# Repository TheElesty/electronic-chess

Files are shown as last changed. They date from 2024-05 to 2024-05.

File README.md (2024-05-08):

# electronic-chess
### Diploma thesis project

This is my implementation for electronic chess board. It uses NFC MFRC522 for pieces detection. UI consist of TFT LCD display, adressable LED and endstops/rotary encoder for input. 

This repository contains all files needed to manufacture, assemble and program electronic chessboard.

Folders contains
- [board_model](board_model/README.md) - all 3D models created in Fusion 360
- [electronic_chess](electronic_chess/README.md) - whole firmware created in Arduino IDE
- [manufacturing](manufacturing/README.md) - all files for 3D printing (prepared in Bambu studio, Anycubic Workshop and LightBurn)
- [pcb_schematics](pcb_schematics/README.md) - all schematics created in Eagle

Each directory has it own README with instructions, tutorials, etc.

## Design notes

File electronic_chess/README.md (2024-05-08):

# Firmware

This folder contains whole firmware of chess board. It's written in Arduino IDE. All used libraryes are in folder libs, you must copy thes lib into Arduino folder in your PC (some libraries are changed and without it is firmware uncompilable).

Program is tested with [earlephilhower arduino-pico](https://github.com/earlephilhower/arduino-pico/) Raspberry Pi Pico core. You need to add board definition for it - pase this link in Arduino IDE -> preferences -> Aditional boards definitions -> https://github.com/earlephilhower/arduino-pico/releases/download/global/package_rp2040_index.json

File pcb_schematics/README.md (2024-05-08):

# Eagle schematics

This folder contains all schematics used board. Either you can open schematic directli or creat new project and paste files from folder Electronic_chess inside it.

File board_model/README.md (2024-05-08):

# Board model

All parts of chess board is modeled in Fusion360. Thes folder contains both Fusion projects and 3mf export of all parts. PCB models are generated from schematics made in Eagle.

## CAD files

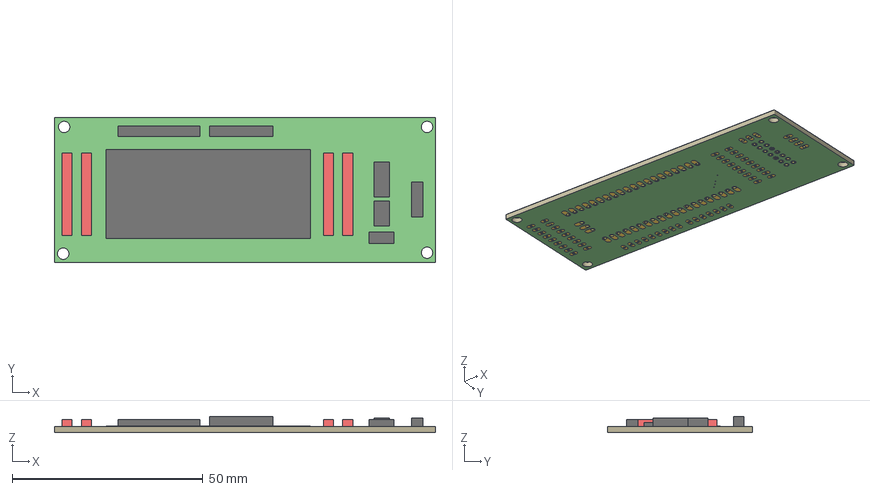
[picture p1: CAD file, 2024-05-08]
board_model/PCB/main_board/main_board v1.3mf
100.0 x 38.0 x 4.31 mm
Board
CopperHoles

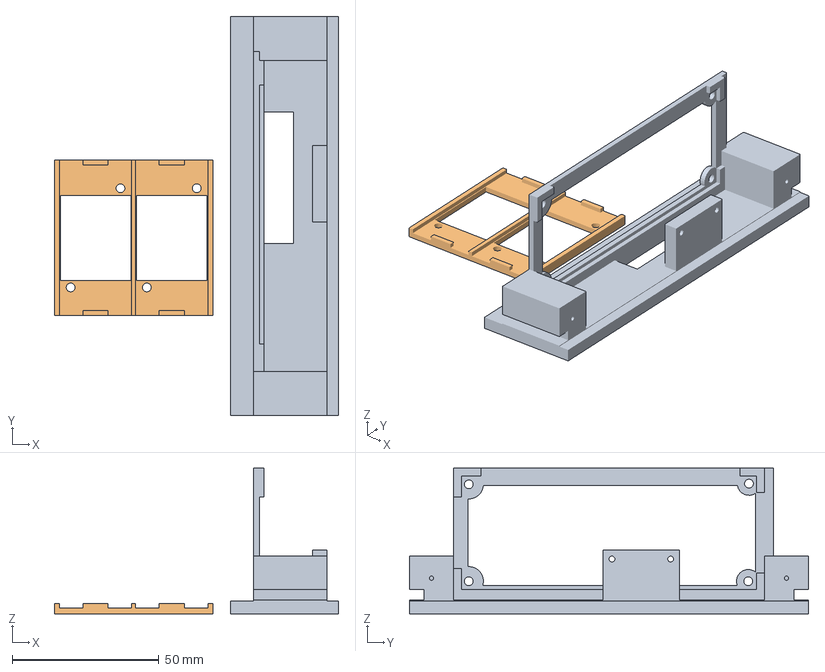
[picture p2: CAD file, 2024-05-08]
manufacturing/printing/chess_board_main_board.3mf
96.8 x 136.0 x 49.7 mm
main_board_holder
powersupply_holder

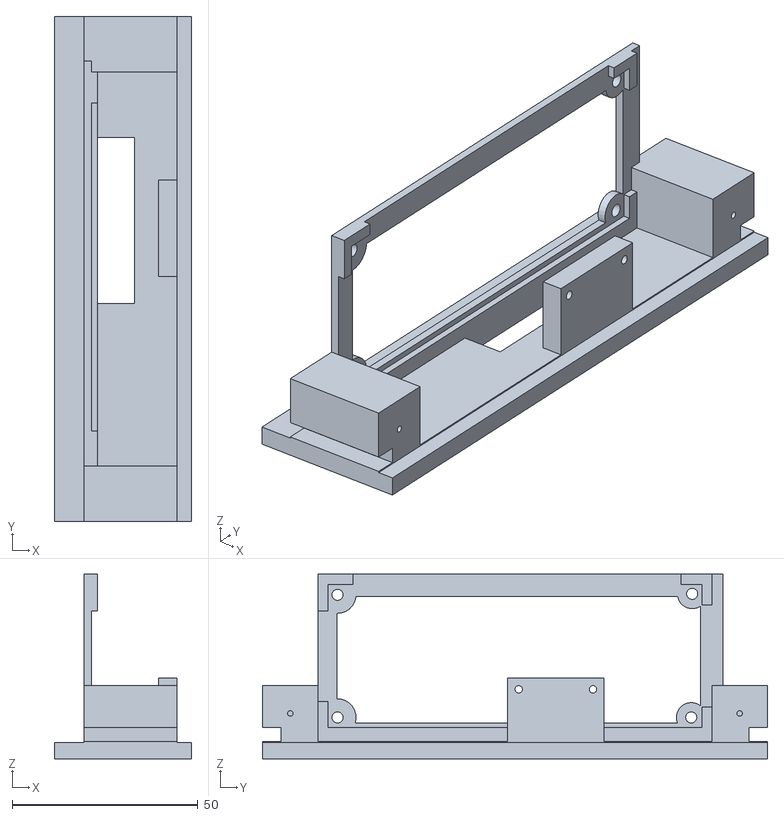
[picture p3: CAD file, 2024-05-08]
manufacturing/printing/raw/chess_board_mainboard_holder.stl
36.9 x 136.0 x 49.7

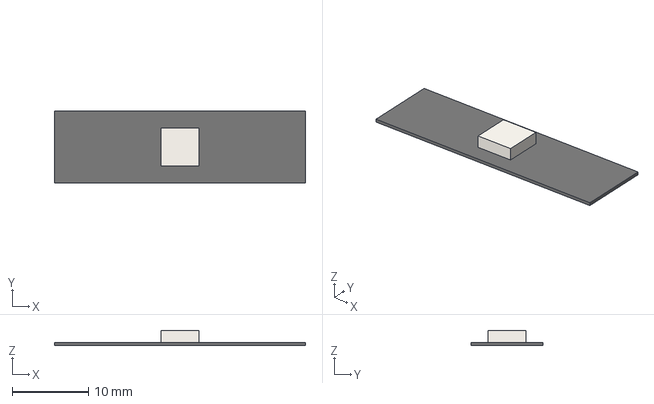
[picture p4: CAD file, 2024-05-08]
board_model/MODELS/Assets/led v2.3mf
33.0 x 9.50 x 2.00 mm

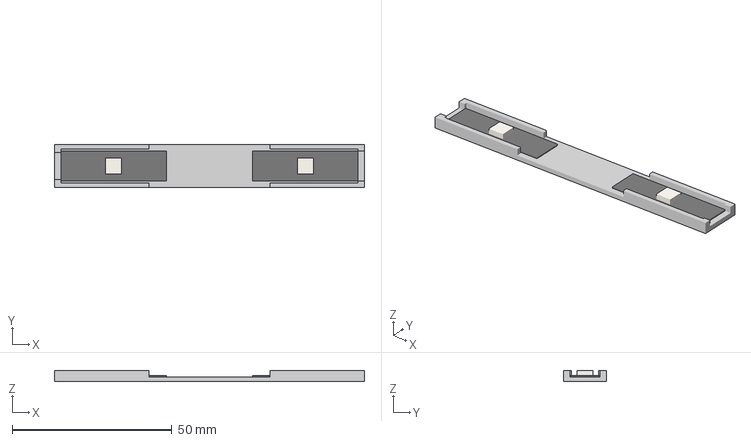
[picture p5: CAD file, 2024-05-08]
board_model/MODELS/led_solderRig v2.3mf
97.0 x 13.5 x 3.50 mm

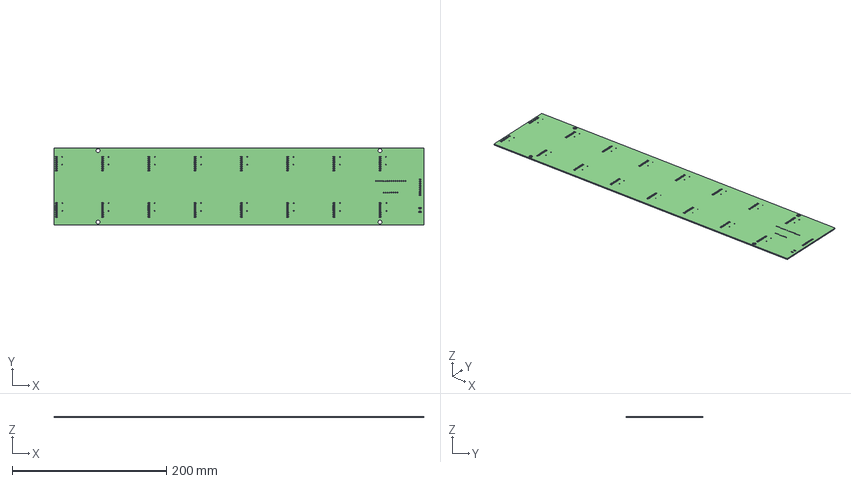
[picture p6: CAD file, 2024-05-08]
board_model/PCB/mux16_board/mux16_board v1.3mf
480.0 x 100.0 x 1.64 mm
Board
CopperHoles

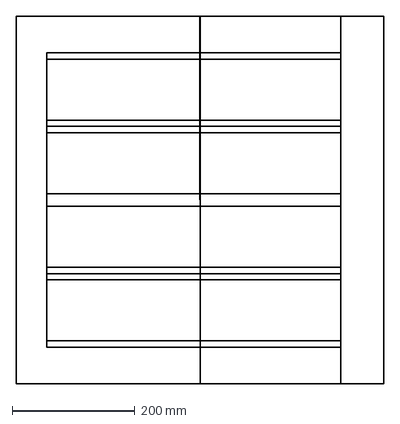
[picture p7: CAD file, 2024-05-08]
manufacturing/laser_cut/raw/bottom_board.dxf
600.0 x 600.0 mm

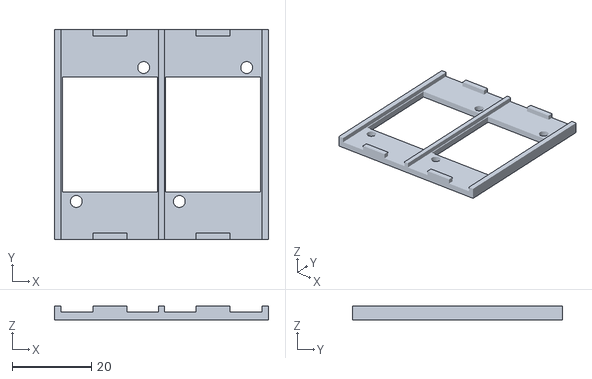
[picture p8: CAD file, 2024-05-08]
manufacturing/printing/raw/chess_board_buckconvertor_holder.stl
54.0 x 53.0 x 3.50

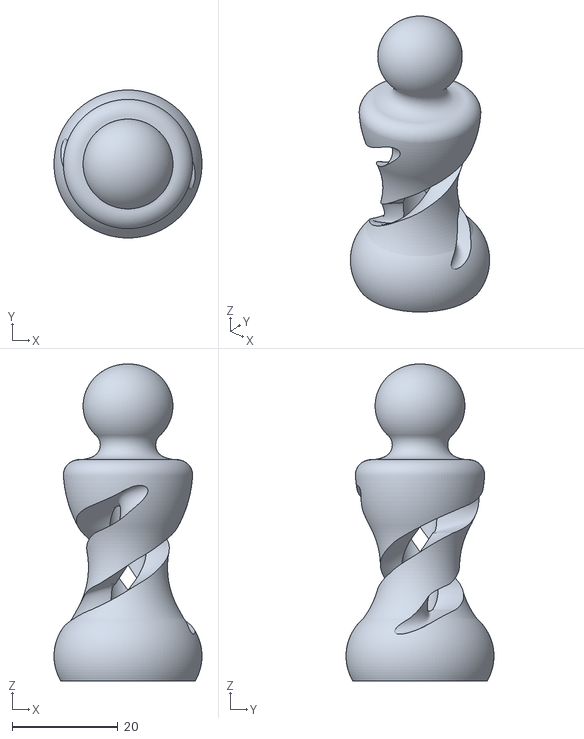
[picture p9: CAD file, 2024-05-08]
manufacturing/printing/raw/pieces/pawn.stl
28.0 x 28.0 x 60.0

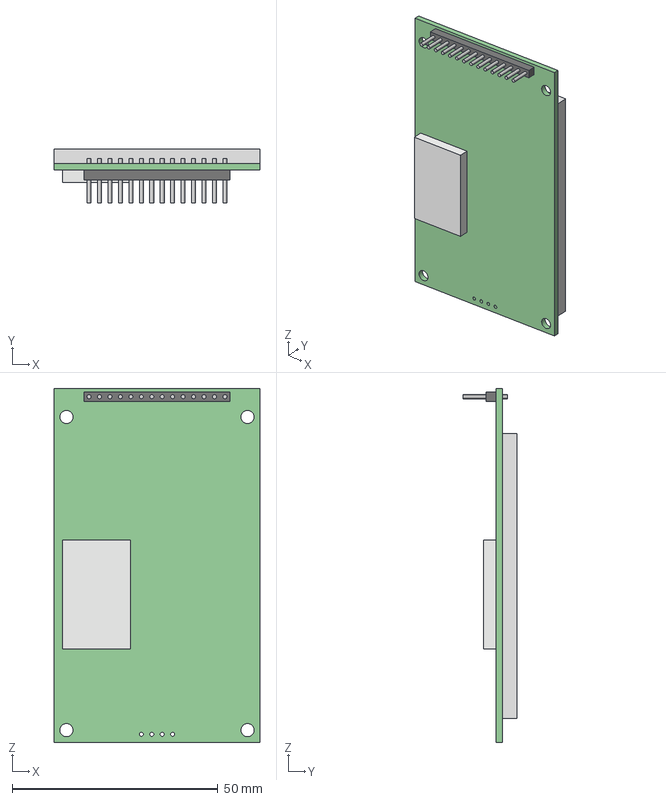
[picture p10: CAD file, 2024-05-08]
board_model/MODELS/Assets/_2,8Zoll TFT SPI.7f793562-e44e-44ae-986e-20ae59d8bd2c v1.3mf
50.0 x 13.1 x 86.0 mm

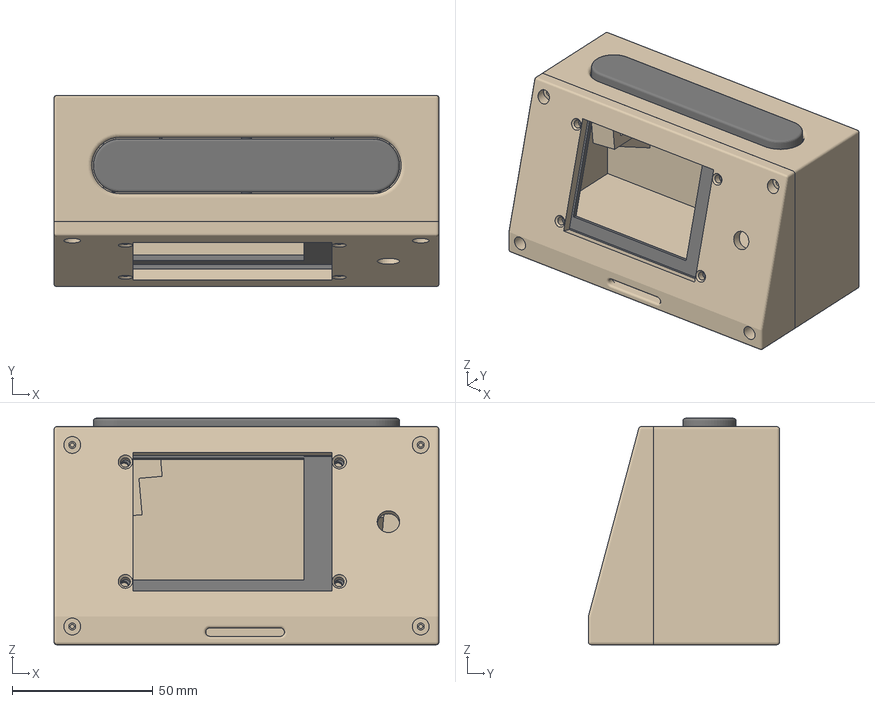
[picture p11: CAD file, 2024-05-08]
board_model/MODELS/chess_clock v14.3mf
137.0 x 68.1 x 80.6 mm
Front_panel
back_panel
hinge
paddle
tft_backplate

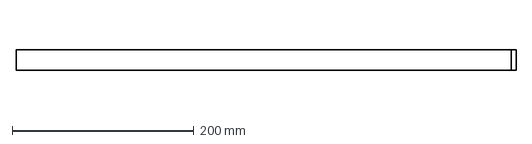
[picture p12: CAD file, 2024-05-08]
manufacturing/laser_cut/raw/side.dxf
550.0 x 22.5 mm

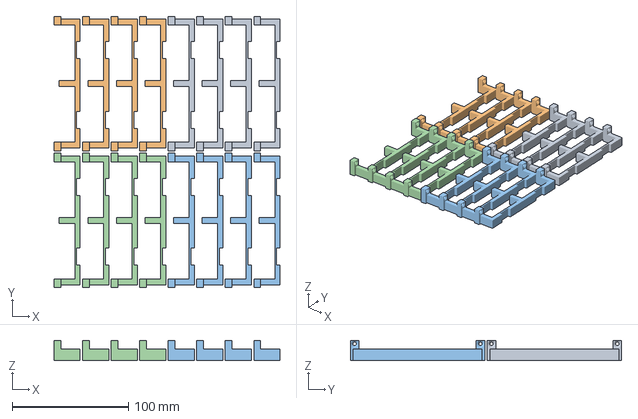
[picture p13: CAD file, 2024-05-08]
manufacturing/printing/chess_board_led_holders.3mf
194.8 x 234.0 x 17.5 mm
Assembly x 4

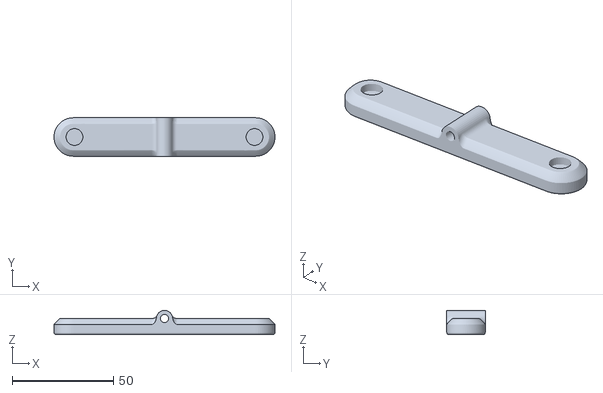
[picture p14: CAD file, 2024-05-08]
manufacturing/printing/raw/chess_clock_paddle.stl
109.0 x 19.0 x 12.0

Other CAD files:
manufacturing/printing/piece_set_2x.3mf
manufacturing/printing/raw/pieces/knight.stl
board_model/MODELS/Assets/_RFID-RC522.cd1ec80f-b667-4655-b6b3-a21b5d1b7a74 v7.3mf
manufacturing/laser_cut/raw/top_board.dxf
board_model/MODELS/Assets/_2,8Zoll TFT SPI.7f793562-e44e-44ae-986e-20ae59d8bd2c v1.f3d
board_model/MODELS/Assets/_RFID-RC522.cd1ec80f-b667-4655-b6b3-a21b5d1b7a74 v7.f3d
board_model/MODELS/Assets/led v2.f3d
board_model/MODELS/chess_clock v14.f3z
board_model/MODELS/led_solderRig v2.f3z
manufacturing/laser_cut/raw/foam.dxf
manufacturing/laser_cut/raw/short_side.dxf
manufacturing/printing/chess_board_mx_holders.3mf
manufacturing/printing/chess_board_sides.3mf
manufacturing/printing/chess_clock.3mf
manufacturing/printing/led_solderRig.3mf
manufacturing/printing/led_support_2x.3mf
manufacturing/printing/raw/SUPPORTED_light_tunnel.stl
manufacturing/printing/raw/chess_board_corner.stl
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

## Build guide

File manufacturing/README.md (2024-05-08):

# Manufacturing

All parts in thes folders are needed for completing chess board, clocks and piece box (with all chess figures). Some files need to be made multiple times. Thes files has number in name that show how many times it should be made.

## Laser cutting
Files are prepared for light burn, black object are meant to buy cut, all other colors are used for engravin. All cut setting need to be changed by user depending on used material - sould be used 4mm playwood. some files has rad color used for marking pieces for assembly.

## Printing
Parts are made on both FDM and SLA printer. All parts has prepared file for printing (specific setting for supports etc. should make user depending on printer), SLA prints has suports premade if needed (light tunnels). All FDM parts are meda from PETG - I don't recomend use of PLA.

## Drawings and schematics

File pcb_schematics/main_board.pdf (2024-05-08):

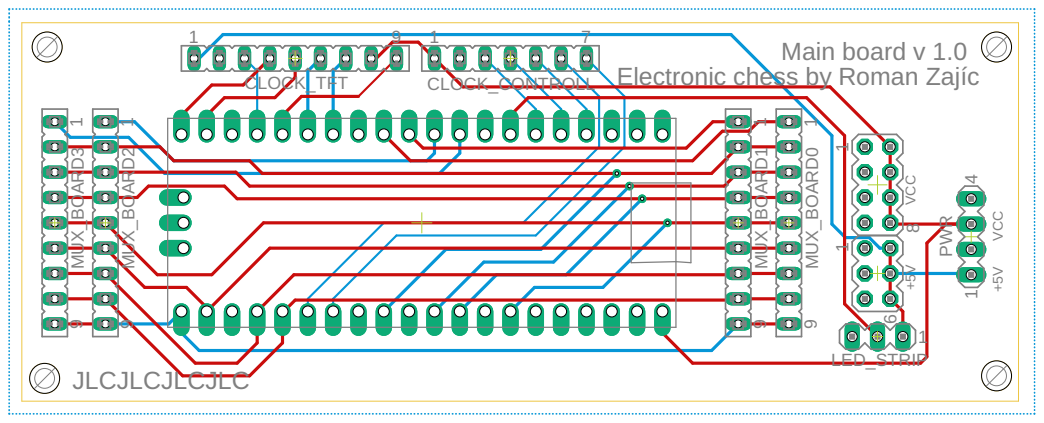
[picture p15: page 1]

Electronic chess by Roman Zajíc

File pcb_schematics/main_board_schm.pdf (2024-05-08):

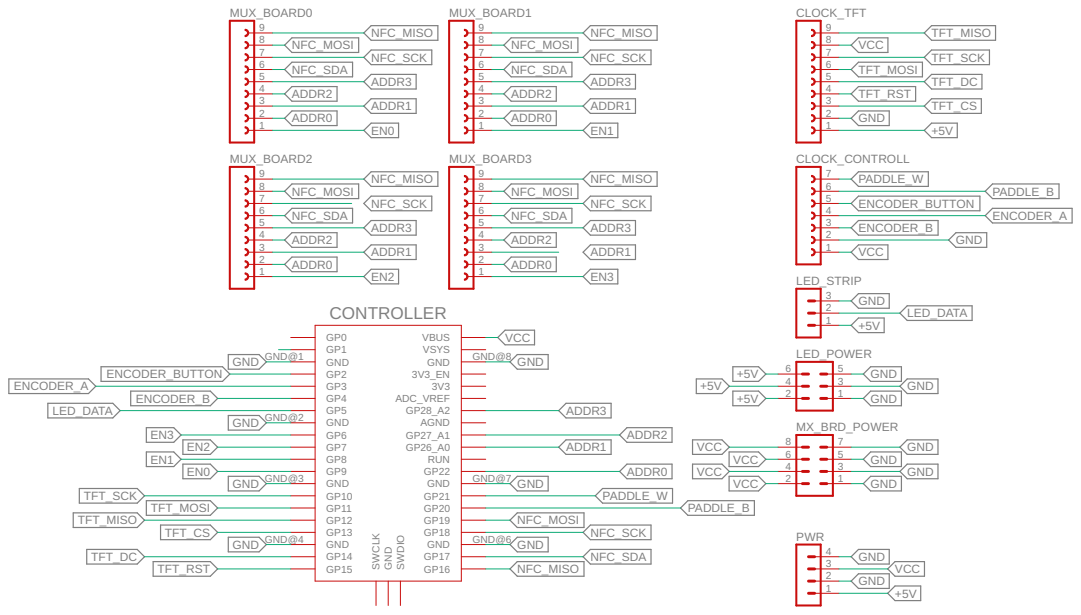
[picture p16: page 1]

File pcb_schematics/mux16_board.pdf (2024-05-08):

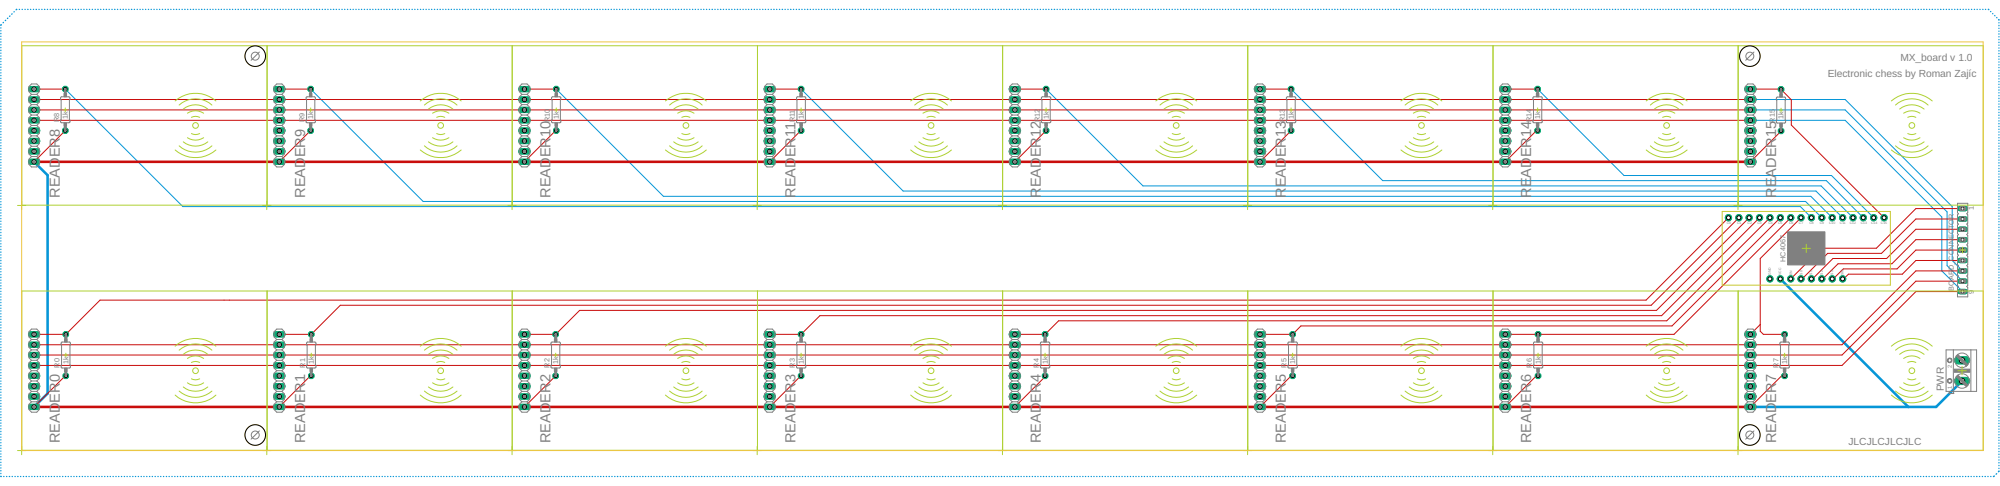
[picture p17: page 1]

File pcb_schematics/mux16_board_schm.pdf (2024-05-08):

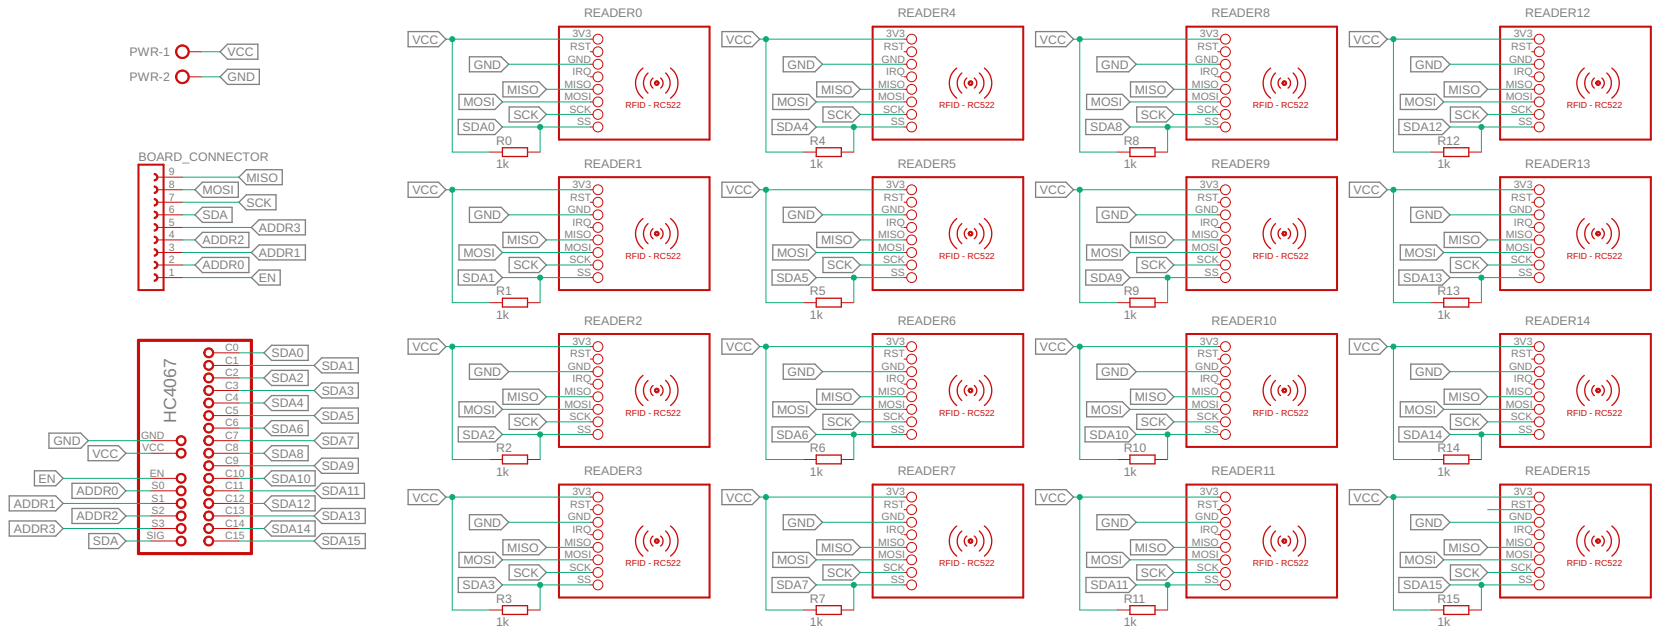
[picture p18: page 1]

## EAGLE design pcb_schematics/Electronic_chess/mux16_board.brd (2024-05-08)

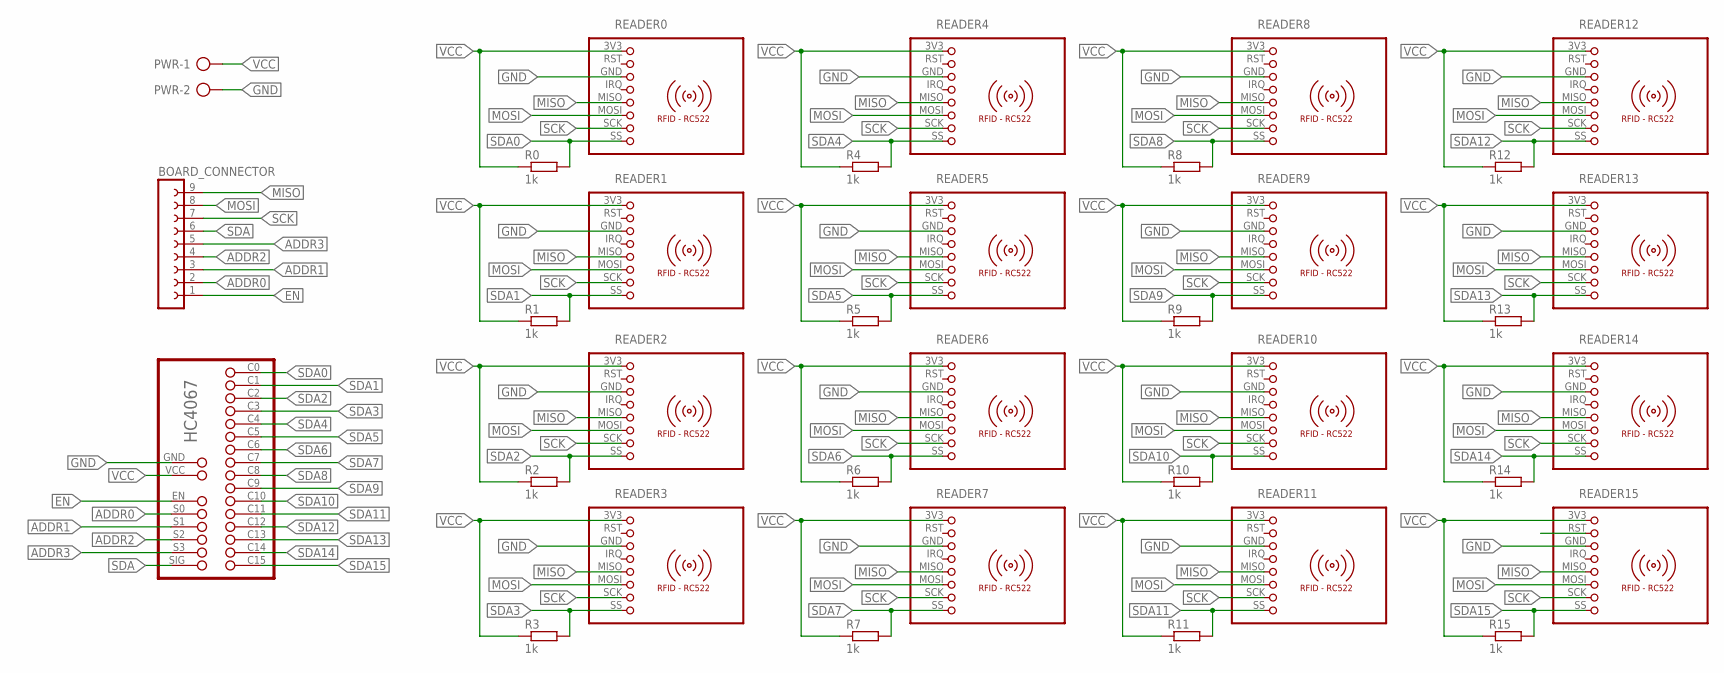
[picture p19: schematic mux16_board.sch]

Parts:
BOARD_CONNECTOR: FE09-1; FE09
PWR: AK500/2
R0, R1, R2, R3, R4, R5, R6, R7, R8, R9, R10, R11, R12, R13, R14, R15: 1k; 0207/10
READER0, READER1, READER2, READER3, READER4, READER5, READER6, READER7, READER8, READER9, READER10, READER11, READER12, READER13, READER14, READER15: RFID-RC522
U$1: HC4067_BREAKOUT_BOARD; ANALOG_MUX_BREAKOUT_HC4067

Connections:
ADDR0: BOARD_CONNECTOR.2, U$1.S0
ADDR1: BOARD_CONNECTOR.3, U$1.S1
ADDR2: BOARD_CONNECTOR.4, U$1.S2
ADDR3: BOARD_CONNECTOR.5, U$1.S3
EN: BOARD_CONNECTOR.1, U$1.EN
GND: PWR.2, READER0.GND (3), READER1.GND (3), READER2.GND (3), READER3.GND (3), READER4.GND (3), READER5.GND (3), READER6.GND (3), READER7.GND (3), READER8.GND (3), READER9.GND (3), READER10.GND (3), READER11.GND (3), READER12.GND (3), READER13.GND (3), READER14.GND (3), READER15.GND (3), U$1.GND
MISO: BOARD_CONNECTOR.9, READER0.MISO (5), READER1.MISO (5), READER2.MISO (5), READER3.MISO (5), READER4.MISO (5), READER5.MISO (5), READER6.MISO (5), READER7.MISO (5), READER8.MISO (5), READER9.MISO (5), READER10.MISO (5), READER11.MISO (5), READER12.MISO (5), READER13.MISO (5), READER14.MISO (5), READER15.MISO (5)
MOSI: BOARD_CONNECTOR.8, READER0.MOSI (6), READER1.MOSI (6), READER2.MOSI (6), READER3.MOSI (6), READER4.MOSI (6), READER5.MOSI (6), READER6.MOSI (6), READER7.MOSI (6), READER8.MOSI (6), READER9.MOSI (6), READER10.MOSI (6), READER11.MOSI (6), READER12.MOSI (6), READER13.MOSI (6), READER14.MOSI (6), READER15.MOSI (6)
RST: READER15.RST (2)
SCK: BOARD_CONNECTOR.7, READER0.SCK (7), READER1.SCK (7), READER2.SCK (7), READER3.SCK (7), READER4.SCK (7), READER5.SCK (7), READER6.SCK (7), READER7.SCK (7), READER8.SCK (7), READER9.SCK (7), READER10.SCK (7), READER11.SCK (7), READER12.SCK (7), READER13.SCK (7), READER14.SCK (7), READER15.SCK (7)
SDA: BOARD_CONNECTOR.6, U$1.SIG
SDA0: R0.2, READER0.SS (8), U$1.C0
SDA1: R1.2, READER1.SS (8), U$1.C1
SDA2: R2.2, READER2.SS (8), U$1.C2
SDA3: R3.2, READER3.SS (8), U$1.C3
SDA4: R4.2, READER4.SS (8), U$1.C4
SDA5: R5.2, READER5.SS (8), U$1.C5
SDA6: R6.2, READER6.SS (8), U$1.C6
SDA7: R7.2, READER7.SS (8), U$1.C7
SDA8: R8.2, READER8.SS (8), U$1.C8
SDA9: R9.2, READER9.SS (8), U$1.C9
SDA10: R10.2, READER10.SS (8), U$1.C10
SDA11: R11.2, READER11.SS (8), U$1.C11
SDA12: R12.2, READER12.SS (8), U$1.C12
SDA13: R13.2, READER13.SS (8), U$1.C13
SDA14: R14.2, READER14.SS (8), U$1.C14
SDA15: R15.2, READER15.SS (8), U$1.C15
VCC: PWR.1, R0.1, R1.1, R2.1, R3.1, R4.1, R5.1, R6.1, R7.1, R8.1, R9.1, R10.1, R11.1, R12.1, R13.1, R14.1, R15.1, READER0.3V3 (1), READER1.3V3 (1), READER2.3V3 (1), READER3.3V3 (1), READER4.3V3 (1), READER5.3V3 (1), READER6.3V3 (1), READER7.3V3 (1), READER8.3V3 (1), READER9.3V3 (1), READER10.3V3 (1), READER11.3V3 (1), READER12.3V3 (1), READER13.3V3 (1), READER14.3V3 (1), READER15.3V3 (1), U$1.VCC

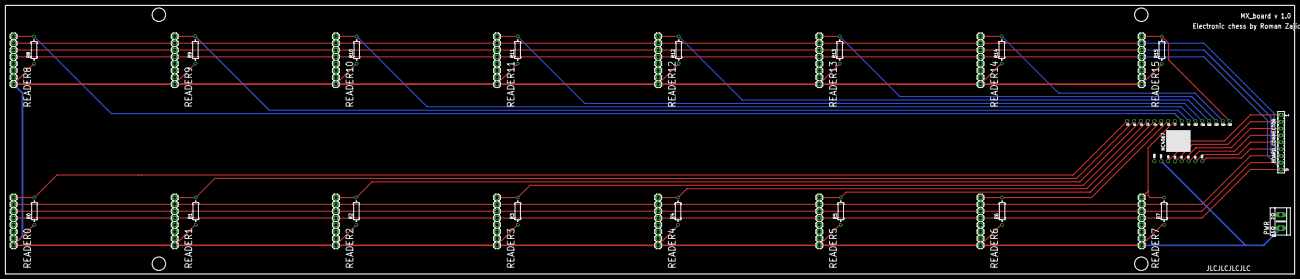
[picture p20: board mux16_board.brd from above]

Board: 2 copper layers, 480.0 x 100.0 mm, 35 parts (0 on the bottom side), 27 nets.

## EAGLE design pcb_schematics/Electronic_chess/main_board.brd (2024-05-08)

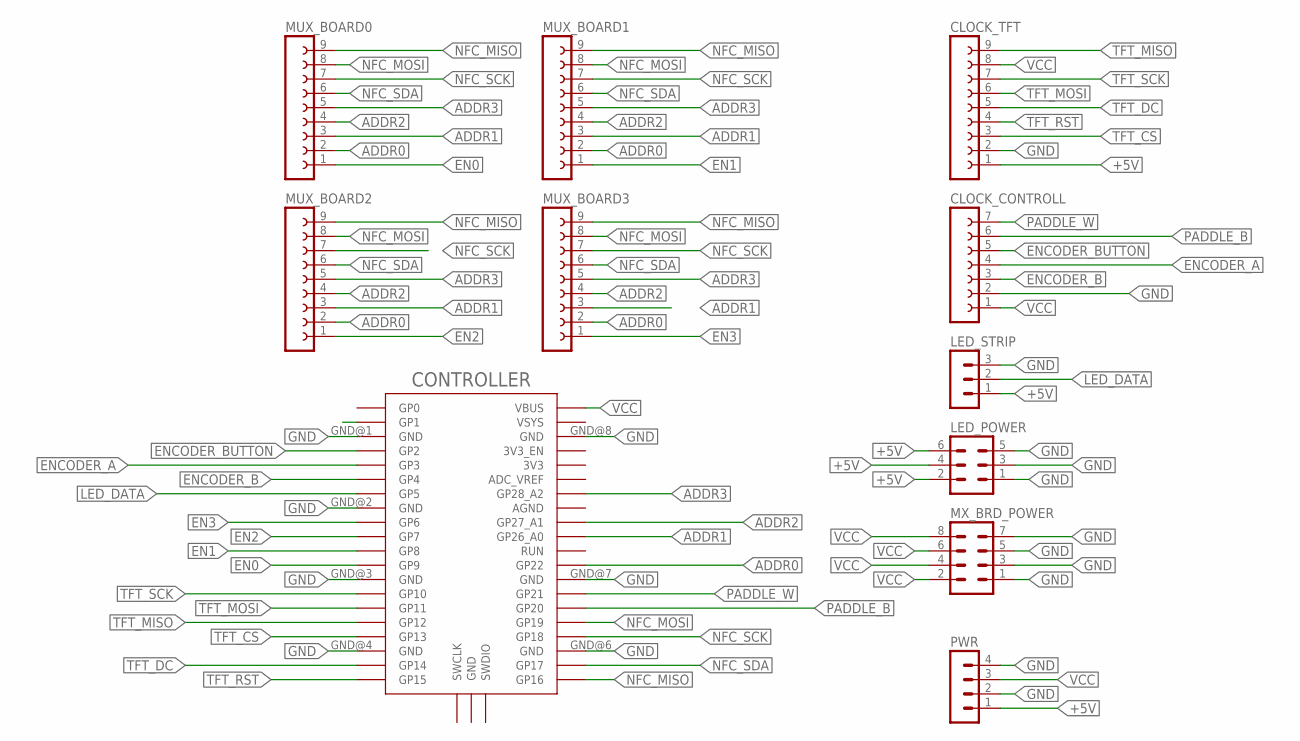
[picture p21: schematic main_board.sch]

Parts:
CLOCK_CONTROLL: FE07-1; FE07
CLOCK_TFT: FE09-1; FE09
CONTROLLER: RPI_PICO_IG-TH; RPI_PICO_TH
LED_POWER: MA03-2
LED_STRIP: MA03-1
MUX_BOARD0, MUX_BOARD1, MUX_BOARD2, MUX_BOARD3: FE09-1; FE09
MX_BRD_POWER: MA04-2
PWR: MA04-1

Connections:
+5V: CLOCK_TFT.1, LED_POWER.2, LED_POWER.4, LED_POWER.6, LED_STRIP.1, PWR.1
ADDR0: CONTROLLER.GP22, MUX_BOARD0.2, MUX_BOARD1.2, MUX_BOARD2.2, MUX_BOARD3.2
ADDR1: CONTROLLER.GP26_A0, MUX_BOARD0.3, MUX_BOARD1.3, MUX_BOARD2.3, MUX_BOARD3.3
ADDR2: CONTROLLER.GP27_A1, MUX_BOARD0.4, MUX_BOARD1.4, MUX_BOARD2.4, MUX_BOARD3.4
ADDR3: CONTROLLER.GP28_A2, MUX_BOARD0.5, MUX_BOARD1.5, MUX_BOARD2.5, MUX_BOARD3.5
EN0: CONTROLLER.GP9, MUX_BOARD0.1
EN1: CONTROLLER.GP8, MUX_BOARD1.1
EN2: CONTROLLER.GP7, MUX_BOARD2.1
EN3: CONTROLLER.GP6, MUX_BOARD3.1
ENCODER_A: CLOCK_CONTROLL.4, CONTROLLER.GP3
ENCODER_B: CLOCK_CONTROLL.3, CONTROLLER.GP4
ENCODER_BUTTON: CLOCK_CONTROLL.5, CONTROLLER.GP2
GND: CLOCK_CONTROLL.2, CLOCK_TFT.2, CONTROLLER.GND@1 (GND), CONTROLLER.GND@2 (GND), CONTROLLER.GND@3 (GND), CONTROLLER.GND@4 (GND), CONTROLLER.GND@6 (GND), CONTROLLER.GND@7 (GND), CONTROLLER.GND@8 (GND), LED_POWER.1, LED_POWER.3, LED_POWER.5, LED_STRIP.3, MX_BRD_POWER.1, MX_BRD_POWER.3, MX_BRD_POWER.5, MX_BRD_POWER.7, PWR.2, PWR.4
LED_DATA: CONTROLLER.GP5, LED_STRIP.2
NFC_MISO: CONTROLLER.GP16, MUX_BOARD0.9, MUX_BOARD1.9, MUX_BOARD2.9, MUX_BOARD3.9
NFC_MOSI: CONTROLLER.GP19, MUX_BOARD0.8, MUX_BOARD1.8, MUX_BOARD2.8, MUX_BOARD3.8
NFC_SCK: CONTROLLER.GP18, MUX_BOARD0.7, MUX_BOARD1.7, MUX_BOARD2.7, MUX_BOARD3.7
NFC_SDA: CONTROLLER.GP17, MUX_BOARD0.6, MUX_BOARD1.6, MUX_BOARD2.6, MUX_BOARD3.6
PADDLE_B: CLOCK_CONTROLL.6, CONTROLLER.GP20
PADDLE_W: CLOCK_CONTROLL.7, CONTROLLER.GP21
TFT_CS: CLOCK_TFT.3, CONTROLLER.GP13
TFT_DC: CLOCK_TFT.5, CONTROLLER.GP14
TFT_MISO: CLOCK_TFT.9, CONTROLLER.GP12
TFT_MOSI: CLOCK_TFT.6, CONTROLLER.GP11
TFT_RST: CLOCK_TFT.4, CONTROLLER.GP15
TFT_SCK: CLOCK_TFT.7, CONTROLLER.GP10
VCC: CLOCK_CONTROLL.1, CLOCK_TFT.8, CONTROLLER.VBUS, MX_BRD_POWER.2, MX_BRD_POWER.4, MX_BRD_POWER.6, MX_BRD_POWER.8, PWR.3

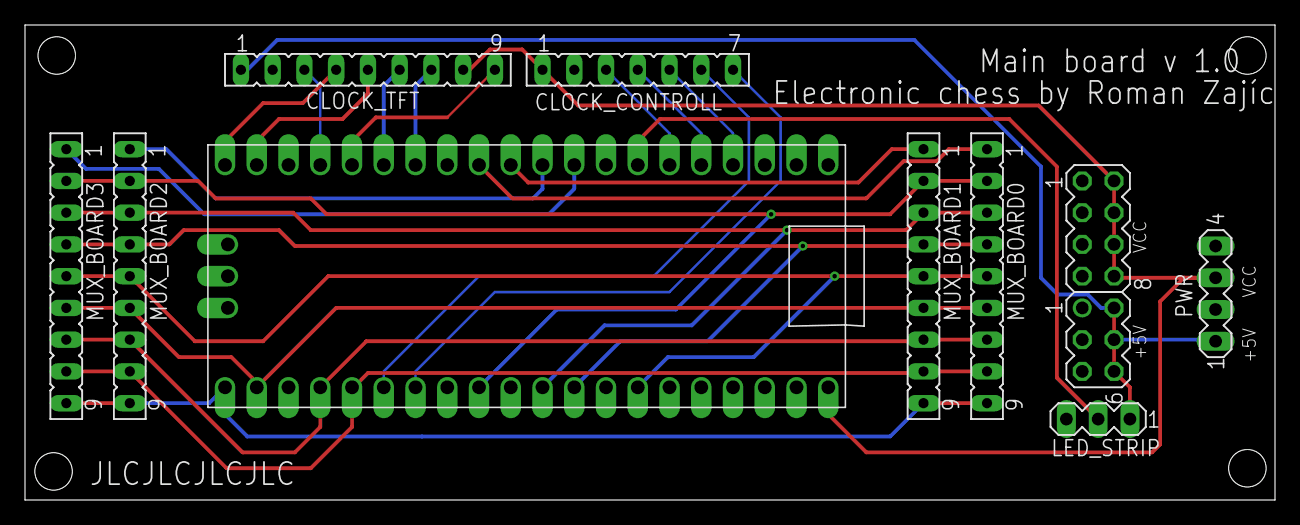
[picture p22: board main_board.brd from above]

Board: 2 copper layers, 100.0 x 38.0 mm, 11 parts (0 on the bottom side), 27 nets.

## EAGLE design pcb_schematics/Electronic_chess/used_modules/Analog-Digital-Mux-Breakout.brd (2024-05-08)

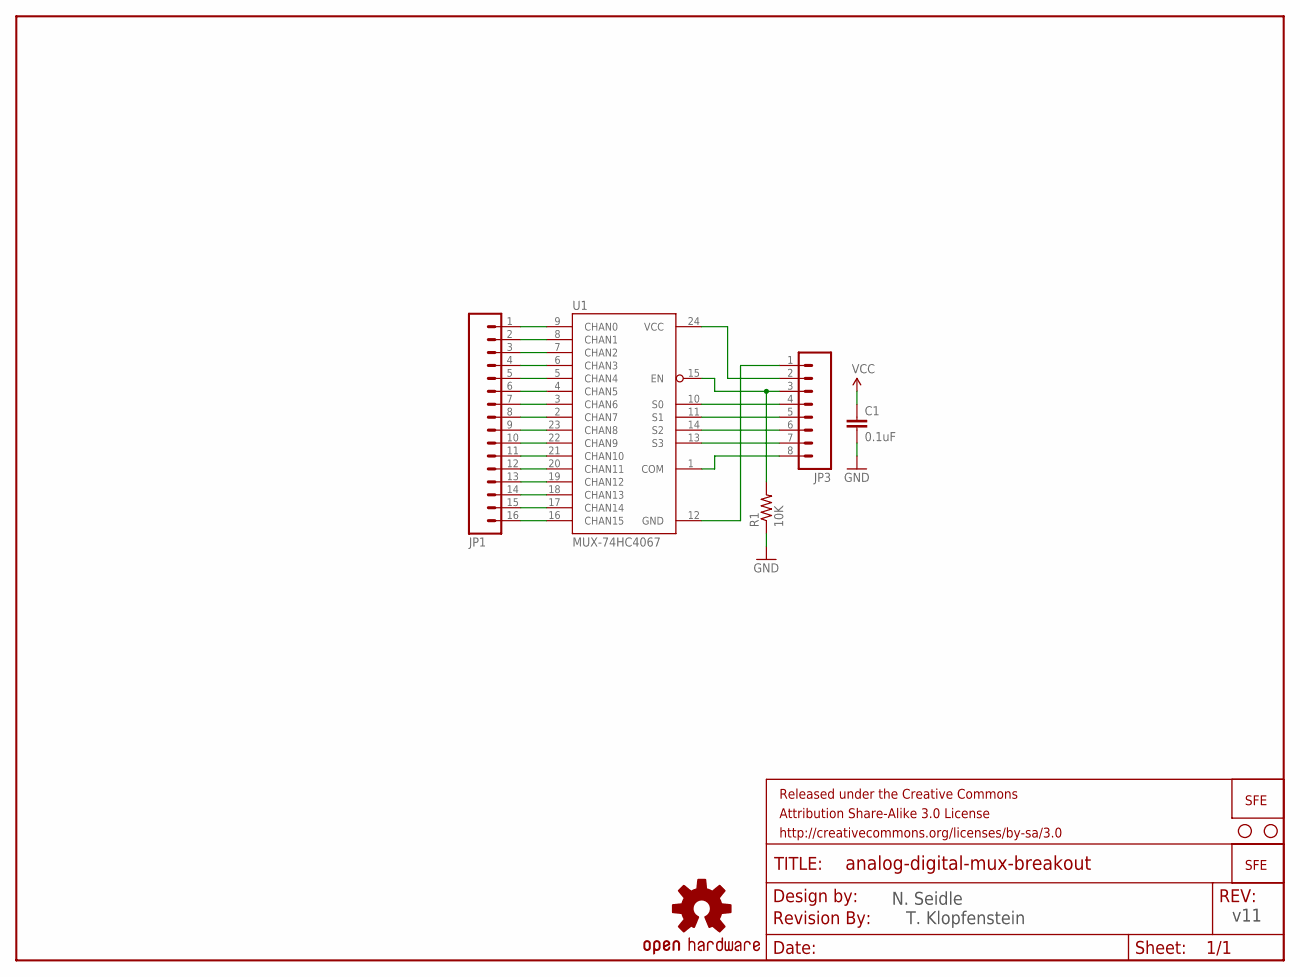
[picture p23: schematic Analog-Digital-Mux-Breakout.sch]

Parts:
C1: 0.1uF; 0603
FRAME1: FRAME-LETTER; CREATIVE_COMMONS
JP1: M16PTH; 1X16
JP3: M081X08; 1X08
LOGO1: OSHW-LOGOL; OSHW-LOGO-L
LOGO2: LOGO-SFESK; SFE-LOGO-FLAME
R1: 10K; 0603
STANDOFF1, STANDOFF2: STAND-OFF
U1: MUX-74HC4067; SSOP24
U$1: LOGO-SFENEW; SFE-NEW-WEBLOGO
U$2: REVISION

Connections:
C0: JP1.1, U1.9 (CHAN0)
C1: JP1.2, U1.8 (CHAN1)
C2: JP1.3, U1.7 (CHAN2)
C3: JP1.4, U1.6 (CHAN3)
C4: JP1.5, U1.5 (CHAN4)
C5: JP1.6, U1.4 (CHAN5)
C6: JP1.7, U1.3 (CHAN6)
C7: JP1.8, U1.2 (CHAN7)
C8: JP1.9, U1.23 (CHAN8)
C9: JP1.10, U1.22 (CHAN9)
C10: JP1.11, U1.21 (CHAN10)
C11: JP1.12, U1.20 (CHAN11)
C12: JP1.13, U1.19 (CHAN12)
C13: JP1.14, U1.18 (CHAN13)
C14: JP1.15, U1.17 (CHAN14)
C15: JP1.16, U1.16 (CHAN15)
EN: JP3.3, R1.2, U1.15 (EN)
GND: C1.2, JP3.1, R1.1, U1.12 (GND)
S0: JP3.4, U1.10 (S0)
S1: JP3.5, U1.11 (S1)
S2: JP3.6, U1.14 (S2)
S3: JP3.7, U1.13 (S3)
SIG: JP3.8, U1.1 (COM)
VCC: C1.1, JP3.2, U1.24 (VCC)

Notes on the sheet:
v11
N. Seidle
T. Klopfenstein

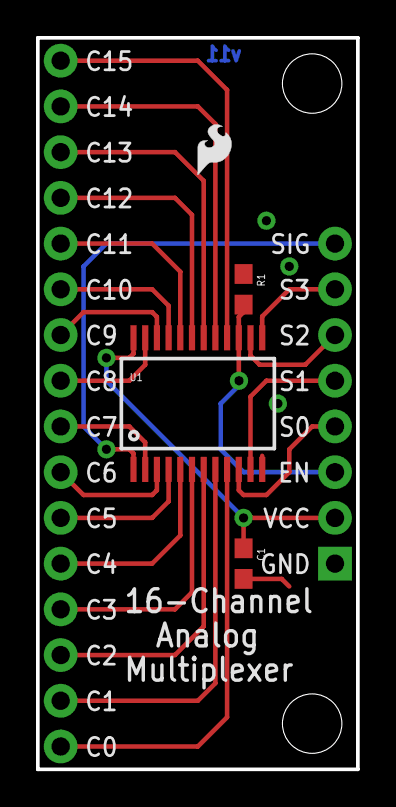
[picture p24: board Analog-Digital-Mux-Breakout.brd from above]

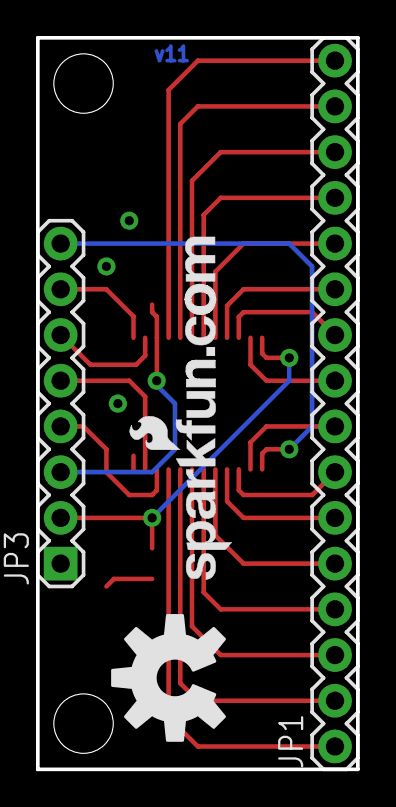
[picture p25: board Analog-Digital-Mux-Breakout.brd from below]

Board: 2 copper layers, 17.8 x 40.6 mm, 12 parts (4 on the bottom side), 24 nets.

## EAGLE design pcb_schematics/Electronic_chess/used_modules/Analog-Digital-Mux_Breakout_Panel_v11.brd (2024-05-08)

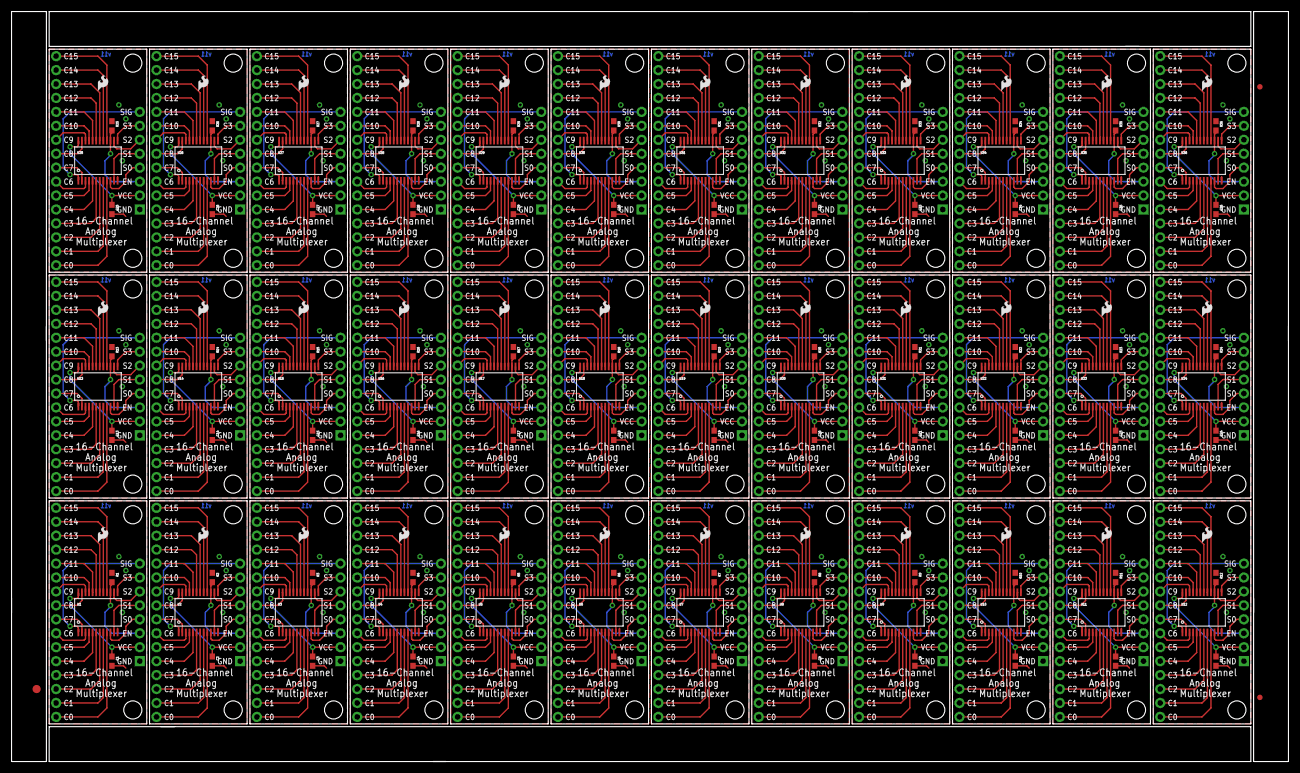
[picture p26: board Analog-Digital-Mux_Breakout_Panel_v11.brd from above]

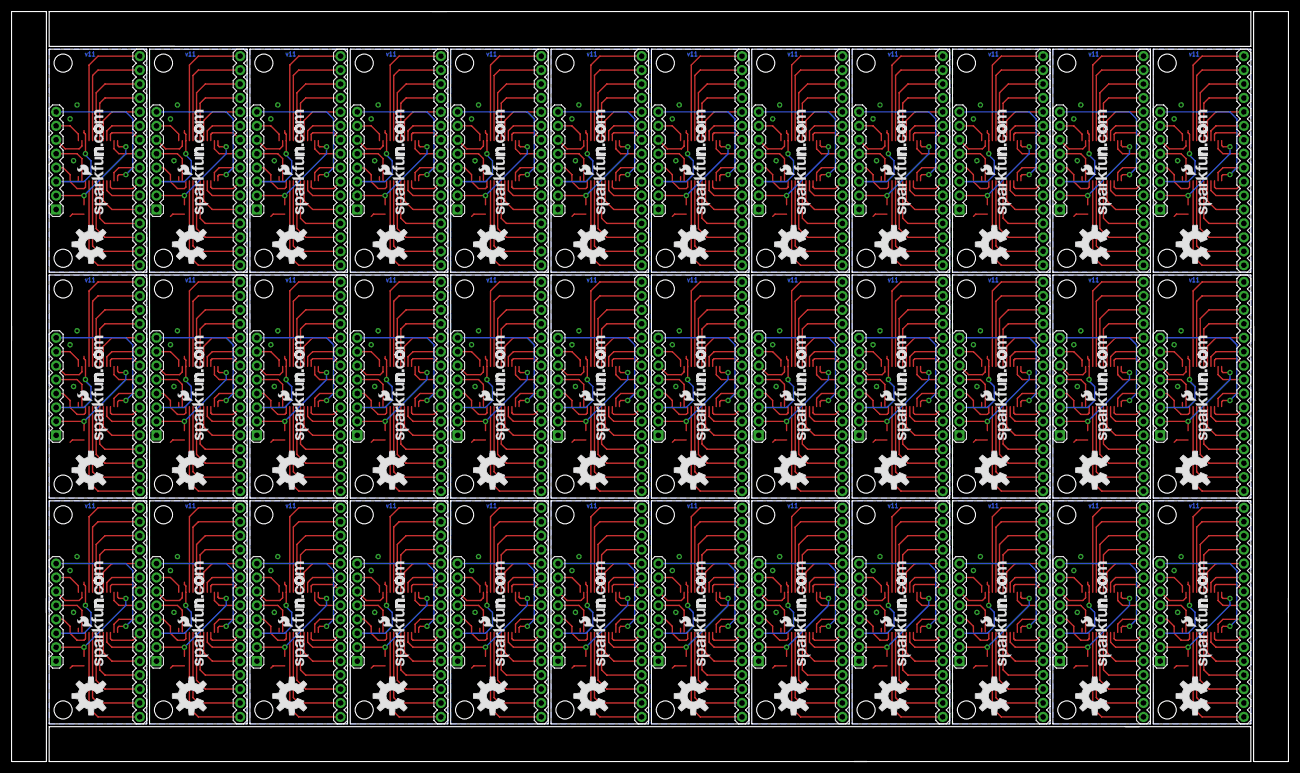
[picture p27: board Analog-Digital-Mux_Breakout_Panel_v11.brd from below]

Board: 2 copper layers, 232.7 x 136.7 mm, 363 parts (144 on the bottom side), 864 nets.

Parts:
C1, C2, C3, C4, C5, C6, C7, C8, C9, C10, C11, C12, C13, C14, C15, C16, C17, C18, C19, C20, C21, C22, C23, C24, C25, C26, C27, C28, C29, C30, C31, C32, C33, C34, C35, C36: 0.1uF; 0603
E$1: FIDUCIAL-1.5X3
E$5, E$6: FIDUCIAL-1X2
JP1, JP2, JP5, JP7, JP9, JP11, JP13, JP15, JP17, JP19, JP21, JP23, JP25, JP27, JP29, JP31, JP33, JP35, JP37, JP39, JP41, JP43, JP45, JP47, JP49, JP51, JP53, JP55, JP57, JP59, JP61, JP63, JP65, JP67, JP69, JP71: 1X16
JP3, JP4, JP6, JP8, JP10, JP12, JP14, JP16, JP18, JP20, JP22, JP24, JP26, JP28, JP30, JP32, JP34, JP36, JP38, JP40, JP42, JP44, JP46, JP48, JP50, JP52, JP54, JP56, JP58, JP60, JP62, JP64, JP66, JP68, JP70, JP72: 1X08
LOGO1, LOGO3, LOGO5, LOGO7, LOGO9, LOGO11, LOGO13, LOGO15, LOGO17, LOGO19, LOGO21, LOGO23, LOGO25, LOGO27, LOGO29, LOGO31, LOGO33, LOGO35, LOGO37, LOGO39, LOGO41, LOGO43, LOGO45, LOGO47, LOGO49, LOGO51, LOGO53, LOGO55, LOGO57, LOGO59, LOGO61, LOGO63, LOGO65, LOGO67, LOGO69, LOGO71: OSHW-LOGOL; OSHW-LOGO-L
LOGO2, LOGO4, LOGO6, LOGO8, LOGO10, LOGO12, LOGO14, LOGO16, LOGO18, LOGO20, LOGO22, LOGO24, LOGO26, LOGO28, LOGO30, LOGO32, LOGO34, LOGO36, LOGO38, LOGO40, LOGO42, LOGO44, LOGO46, LOGO48, LOGO50, LOGO52, LOGO54, LOGO56, LOGO58, LOGO60, LOGO62, LOGO64, LOGO66, LOGO68, LOGO70, LOGO72: LOGO-SFESK; SFE-LOGO-FLAME
R1, R2, R3, R4, R5, R6, R7, R8, R9, R10, R11, R12, R13, R14, R15, R16, R17, R18, R19, R20, R21, R22, R23, R24, R25, R26, R27, R28, R29, R30, R31, R32, R33, R34, R35, R36: 10K; 0603
STANDOFF1, STANDOFF2, STANDOFF3, STANDOFF4, STANDOFF5, STANDOFF6, STANDOFF7, STANDOFF8, STANDOFF9, STANDOFF10, STANDOFF11, STANDOFF12, STANDOFF13, STANDOFF14, STANDOFF15, STANDOFF16, STANDOFF17, STANDOFF18, STANDOFF19, STANDOFF20, STANDOFF21, STANDOFF22, STANDOFF23, STANDOFF24, STANDOFF25, STANDOFF26, STANDOFF27, STANDOFF28, STANDOFF29, STANDOFF30, STANDOFF31, STANDOFF32, STANDOFF33, STANDOFF34, STANDOFF35, STANDOFF36, STANDOFF37, STANDOFF38, STANDOFF39, STANDOFF40, STANDOFF41, STANDOFF42, STANDOFF43, STANDOFF44, STANDOFF45, STANDOFF46, STANDOFF47, STANDOFF48, STANDOFF49, STANDOFF50, STANDOFF51, STANDOFF52, STANDOFF53, STANDOFF54, STANDOFF55, STANDOFF56, STANDOFF57, STANDOFF58, STANDOFF59, STANDOFF60, STANDOFF61, STANDOFF62, STANDOFF63, STANDOFF64, STANDOFF65, STANDOFF66, STANDOFF67, STANDOFF68, STANDOFF69, STANDOFF70, STANDOFF71, STANDOFF72: STAND-OFF
U1, U2, U3, U4, U5, U6, U7, U8, U9, U10, U11, U12, U13, U14, U15, U16, U17, U18, U19, U20, U21, U22, U23, U24, U25, U26, U27, U28, U29, U30, U31, U32, U33, U34, U35, U36: MUX-74HC4067; SSOP24
U$1, U$2, U$3, U$4, U$5, U$6, U$7, U$8, U$9, U$10, U$11, U$12, U$13, U$14, U$15, U$16, U$17, U$18, U$19, U$20, U$21, U$22, U$23, U$24, U$25, U$26, U$27, U$28, U$29, U$30, U$31, U$32, U$33, U$34, U$35, U$36: LOGO-SFENEW; SFE-NEW-WEBLOGO

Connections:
C0: JP1.1, U1.9
C1: JP1.2, U1.8
C2: JP1.3, U1.7
C3: JP1.4, U1.6
C4: JP1.5, U1.5
C5: JP1.6, U1.4
C6: JP1.7, U1.3
C7: JP1.8, U1.2
C8: JP1.9, U1.23
C9: JP1.10, U1.22
C10: JP1.11, U1.21
C11: JP1.12, U1.20
C12: JP1.13, U1.19
C13: JP1.14, U1.18
C14: JP1.15, U1.17
C15: JP1.16, U1.16
C16: JP2.1, U2.9
C17: JP2.2, U2.8
C18: JP2.3, U2.7
C19: JP2.4, U2.6
C20: JP2.5, U2.5
C21: JP2.6, U2.4
C22: JP2.7, U2.3
C23: JP2.8, U2.2
C24: JP2.9, U2.23
C25: JP2.10, U2.22
C26: JP2.11, U2.21
C27: JP2.12, U2.20
C28: JP2.13, U2.19
C29: JP2.14, U2.18
C30: JP2.15, U2.17
C31: JP2.16, U2.16
C32: JP5.1, U3.9
C33: JP5.2, U3.8
C34: JP5.3, U3.7
C35: JP5.4, U3.6
C36: JP5.5, U3.5
C37: JP5.6, U3.4
C38: JP5.7, U3.3
C39: JP5.8, U3.2
C40: JP5.9, U3.23
C41: JP5.10, U3.22
C42: JP5.11, U3.21
C43: JP5.12, U3.20
C44: JP5.13, U3.19
C45: JP5.14, U3.18
C46: JP5.15, U3.17
C47: JP5.16, U3.16
C48: JP7.1, U4.9
C49: JP7.2, U4.8
C50: JP7.3, U4.7
C51: JP7.4, U4.6
C52: JP7.5, U4.5
C53: JP7.6, U4.4
C54: JP7.7, U4.3
C55: JP7.8, U4.2
C56: JP7.9, U4.23
C57: JP7.10, U4.22
C58: JP7.11, U4.21
C59: JP7.12, U4.20
C60: JP7.13, U4.19
C61: JP7.14, U4.18
C62: JP7.15, U4.17
C63: JP7.16, U4.16
C64: JP9.1, U5.9
C65: JP9.2, U5.8
C66: JP9.3, U5.7
C67: JP9.4, U5.6
C68: JP9.5, U5.5
C69: JP9.6, U5.4
C70: JP9.7, U5.3
C71: JP9.8, U5.2
C72: JP9.9, U5.23
C73: JP9.10, U5.22
C74: JP9.11, U5.21
C75: JP9.12, U5.20
C76: JP9.13, U5.19
C77: JP9.14, U5.18
C78: JP9.15, U5.17
C79: JP9.16, U5.16
C80: JP11.1, U6.9
C81: JP11.2, U6.8
C82: JP11.3, U6.7
C83: JP11.4, U6.6
C84: JP11.5, U6.5
C85: JP11.6, U6.4
C86: JP11.7, U6.3
C87: JP11.8, U6.2
C88: JP11.9, U6.23
C89: JP11.10, U6.22
C90: JP11.11, U6.21
C91: JP11.12, U6.20
C92: JP11.13, U6.19
C93: JP11.14, U6.18
C94: JP11.15, U6.17
C95: JP11.16, U6.16
C96: JP13.1, U7.9
C97: JP13.2, U7.8
C98: JP13.3, U7.7
C99: JP13.4, U7.6
C100: JP13.5, U7.5
C101: JP13.6, U7.4
C102: JP13.7, U7.3
C103: JP13.8, U7.2
C104: JP13.9, U7.23
C105: JP13.10, U7.22
C106: JP13.11, U7.21
C107: JP13.12, U7.20
C108: JP13.13, U7.19
C109: JP13.14, U7.18
C110: JP13.15, U7.17
C111: JP13.16, U7.16
C112: JP15.1, U8.9
C113: JP15.2, U8.8
C114: JP15.3, U8.7
C115: JP15.4, U8.6
C116: JP15.5, U8.5
C117: JP15.6, U8.4
C118: JP15.7, U8.3
C119: JP15.8, U8.2
C120: JP15.9, U8.23
C121: JP15.10, U8.22
C122: JP15.11, U8.21
C123: JP15.12, U8.20
C124: JP15.13, U8.19
C125: JP15.14, U8.18
C126: JP15.15, U8.17
C127: JP15.16, U8.16
C128: JP17.1, U9.9
C129: JP17.2, U9.8
C130: JP17.3, U9.7
C131: JP17.4, U9.6
C132: JP17.5, U9.5
C133: JP17.6, U9.4
C134: JP17.7, U9.3
C135: JP17.8, U9.2
C136: JP17.9, U9.23
C137: JP17.10, U9.22
C138: JP17.11, U9.21
C139: JP17.12, U9.20
C140: JP17.13, U9.19
C141: JP17.14, U9.18
C142: JP17.15, U9.17
C143: JP17.16, U9.16
C144: JP19.1, U10.9
C145: JP19.2, U10.8
C146: JP19.3, U10.7
C147: JP19.4, U10.6
C148: JP19.5, U10.5
C149: JP19.6, U10.4
C150: JP19.7, U10.3
C151: JP19.8, U10.2
C152: JP19.9, U10.23
C153: JP19.10, U10.22
C154: JP19.11, U10.21
C155: JP19.12, U10.20
C156: JP19.13, U10.19
C157: JP19.14, U10.18
C158: JP19.15, U10.17
C159: JP19.16, U10.16
C160: JP21.1, U11.9
C161: JP21.2, U11.8
C162: JP21.3, U11.7
C163: JP21.4, U11.6
C164: JP21.5, U11.5
C165: JP21.6, U11.4
C166: JP21.7, U11.3
C167: JP21.8, U11.2
C168: JP21.9, U11.23
C169: JP21.10, U11.22
C170: JP21.11, U11.21
C171: JP21.12, U11.20
C172: JP21.13, U11.19
C173: JP21.14, U11.18
C174: JP21.15, U11.17
C175: JP21.16, U11.16
C176: JP23.1, U12.9
C177: JP23.2, U12.8
C178: JP23.3, U12.7
C179: JP23.4, U12.6
C180: JP23.5, U12.5
C181: JP23.6, U12.4
C182: JP23.7, U12.3
C183: JP23.8, U12.2
C184: JP23.9, U12.23
C185: JP23.10, U12.22
C186: JP23.11, U12.21
C187: JP23.12, U12.20
C188: JP23.13, U12.19
C189: JP23.14, U12.18
C190: JP23.15, U12.17
C191: JP23.16, U12.16
C192: JP25.1, U13.9
C193: JP25.2, U13.8
C194: JP25.3, U13.7
C195: JP25.4, U13.6
C196: JP25.5, U13.5
C197: JP25.6, U13.4
C198: JP25.7, U13.3
C199: JP25.8, U13.2
C200: JP25.9, U13.23
C201: JP25.10, U13.22
C202: JP25.11, U13.21
C203: JP25.12, U13.20
C204: JP25.13, U13.19
C205: JP25.14, U13.18
C206: JP25.15, U13.17
C207: JP25.16, U13.16
C208: JP27.1, U14.9
C209: JP27.2, U14.8
C210: JP27.3, U14.7
C211: JP27.4, U14.6
C212: JP27.5, U14.5
C213: JP27.6, U14.4
C214: JP27.7, U14.3
C215: JP27.8, U14.2
C216: JP27.9, U14.23
C217: JP27.10, U14.22
C218: JP27.11, U14.21
C219: JP27.12, U14.20
C220: JP27.13, U14.19
C221: JP27.14, U14.18
C222: JP27.15, U14.17
C223: JP27.16, U14.16
C224: JP29.1, U15.9
C225: JP29.2, U15.8
C226: JP29.3, U15.7
C227: JP29.4, U15.6
C228: JP29.5, U15.5
C229: JP29.6, U15.4
C230: JP29.7, U15.3
C231: JP29.8, U15.2
C232: JP29.9, U15.23
C233: JP29.10, U15.22
C234: JP29.11, U15.21
C235: JP29.12, U15.20
C236: JP29.13, U15.19
C237: JP29.14, U15.18
C238: JP29.15, U15.17
C239: JP29.16, U15.16
C240: JP31.1, U16.9
C241: JP31.2, U16.8
C242: JP31.3, U16.7
C243: JP31.4, U16.6
C244: JP31.5, U16.5
C245: JP31.6, U16.4
C246: JP31.7, U16.3
C247: JP31.8, U16.2
C248: JP31.9, U16.23
C249: JP31.10, U16.22
C250: JP31.11, U16.21
C251: JP31.12, U16.20
C252: JP31.13, U16.19
C253: JP31.14, U16.18
C254: JP31.15, U16.17
C255: JP31.16, U16.16
C256: JP33.1, U17.9
C257: JP33.2, U17.8
C258: JP33.3, U17.7
C259: JP33.4, U17.6
C260: JP33.5, U17.5
C261: JP33.6, U17.4
C262: JP33.7, U17.3
C263: JP33.8, U17.2
C264: JP33.9, U17.23
C265: JP33.10, U17.22
C266: JP33.11, U17.21
C267: JP33.12, U17.20
C268: JP33.13, U17.19
C269: JP33.14, U17.18
C270: JP33.15, U17.17
C271: JP33.16, U17.16
C272: JP35.1, U18.9
C273: JP35.2, U18.8
C274: JP35.3, U18.7
C275: JP35.4, U18.6
C276: JP35.5, U18.5
C277: JP35.6, U18.4
C278: JP35.7, U18.3
C279: JP35.8, U18.2
C280: JP35.9, U18.23
C281: JP35.10, U18.22
C282: JP35.11, U18.21
C283: JP35.12, U18.20
C284: JP35.13, U18.19
C285: JP35.14, U18.18
C286: JP35.15, U18.17
C287: JP35.16, U18.16
C288: JP37.1, U19.9
C289: JP37.2, U19.8
C290: JP37.3, U19.7
C291: JP37.4, U19.6
C292: JP37.5, U19.5
C293: JP37.6, U19.4
C294: JP37.7, U19.3
C295: JP37.8, U19.2
C296: JP37.9, U19.23
C297: JP37.10, U19.22
C298: JP37.11, U19.21
C299: JP37.12, U19.20
C300: JP37.13, U19.19
C301: JP37.14, U19.18
C302: JP37.15, U19.17
C303: JP37.16, U19.16
C304: JP39.1, U20.9
C305: JP39.2, U20.8
C306: JP39.3, U20.7
C307: JP39.4, U20.6
C308: JP39.5, U20.5
C309: JP39.6, U20.4
C310: JP39.7, U20.3
C311: JP39.8, U20.2
C312: JP39.9, U20.23
C313: JP39.10, U20.22
C314: JP39.11, U20.21
C315: JP39.12, U20.20
C316: JP39.13, U20.19
C317: JP39.14, U20.18
C318: JP39.15, U20.17
C319: JP39.16, U20.16
C320: JP41.1, U21.9
C321: JP41.2, U21.8
C322: JP41.3, U21.7
C323: JP41.4, U21.6
C324: JP41.5, U21.5
C325: JP41.6, U21.4
C326: JP41.7, U21.3
C327: JP41.8, U21.2
C328: JP41.9, U21.23
C329: JP41.10, U21.22
C330: JP41.11, U21.21
C331: JP41.12, U21.20
C332: JP41.13, U21.19
C333: JP41.14, U21.18
C334: JP41.15, U21.17
C335: JP41.16, U21.16
C336: JP43.1, U22.9
C337: JP43.2, U22.8
C338: JP43.3, U22.7
C339: JP43.4, U22.6
C340: JP43.5, U22.5
C341: JP43.6, U22.4
C342: JP43.7, U22.3
C343: JP43.8, U22.2
C344: JP43.9, U22.23
C345: JP43.10, U22.22
C346: JP43.11, U22.21
C347: JP43.12, U22.20
C348: JP43.13, U22.19
C349: JP43.14, U22.18
C350: JP43.15, U22.17
C351: JP43.16, U22.16
C352: JP45.1, U23.9
C353: JP45.2, U23.8
C354: JP45.3, U23.7
C355: JP45.4, U23.6
C356: JP45.5, U23.5
C357: JP45.6, U23.4
C358: JP45.7, U23.3
C359: JP45.8, U23.2
C360: JP45.9, U23.23
C361: JP45.10, U23.22
C362: JP45.11, U23.21
C363: JP45.12, U23.20
C364: JP45.13, U23.19
C365: JP45.14, U23.18
C366: JP45.15, U23.17
C367: JP45.16, U23.16
C368: JP47.1, U24.9
C369: JP47.2, U24.8
C370: JP47.3, U24.7
C371: JP47.4, U24.6
C372: JP47.5, U24.5
C373: JP47.6, U24.4
C374: JP47.7, U24.3
C375: JP47.8, U24.2
C376: JP47.9, U24.23
C377: JP47.10, U24.22
C378: JP47.11, U24.21
C379: JP47.12, U24.20
C380: JP47.13, U24.19
C381: JP47.14, U24.18
C382: JP47.15, U24.17
C383: JP47.16, U24.16
C384: JP49.1, U25.9
C385: JP49.2, U25.8
C386: JP49.3, U25.7
C387: JP49.4, U25.6
C388: JP49.5, U25.5
C389: JP49.6, U25.4
C390: JP49.7, U25.3
C391: JP49.8, U25.2
C392: JP49.9, U25.23
C393: JP49.10, U25.22
C394: JP49.11, U25.21
C395: JP49.12, U25.20
C396: JP49.13, U25.19
C397: JP49.14, U25.18
C398: JP49.15, U25.17
C399: JP49.16, U25.16
C400: JP51.1, U26.9
C401: JP51.2, U26.8
C402: JP51.3, U26.7
C403: JP51.4, U26.6
C404: JP51.5, U26.5
C405: JP51.6, U26.4
C406: JP51.7, U26.3
C407: JP51.8, U26.2
C408: JP51.9, U26.23
C409: JP51.10, U26.22
C410: JP51.11, U26.21
C411: JP51.12, U26.20
C412: JP51.13, U26.19
C413: JP51.14, U26.18
C414: JP51.15, U26.17
C415: JP51.16, U26.16
C416: JP53.1, U27.9
C417: JP53.2, U27.8
C418: JP53.3, U27.7
C419: JP53.4, U27.6
C420: JP53.5, U27.5
C421: JP53.6, U27.4
C422: JP53.7, U27.3
C423: JP53.8, U27.2
C424: JP53.9, U27.23
C425: JP53.10, U27.22
C426: JP53.11, U27.21
C427: JP53.12, U27.20
C428: JP53.13, U27.19
C429: JP53.14, U27.18
C430: JP53.15, U27.17
C431: JP53.16, U27.16
C432: JP55.1, U28.9
C433: JP55.2, U28.8
C434: JP55.3, U28.7
C435: JP55.4, U28.6
C436: JP55.5, U28.5
C437: JP55.6, U28.4
C438: JP55.7, U28.3
C439: JP55.8, U28.2
C440: JP55.9, U28.23
C441: JP55.10, U28.22
C442: JP55.11, U28.21
C443: JP55.12, U28.20
C444: JP55.13, U28.19
C445: JP55.14, U28.18
C446: JP55.15, U28.17
C447: JP55.16, U28.16
C448: JP57.1, U29.9
C449: JP57.2, U29.8
C450: JP57.3, U29.7
C451: JP57.4, U29.6
C452: JP57.5, U29.5
C453: JP57.6, U29.4
C454: JP57.7, U29.3
C455: JP57.8, U29.2
C456: JP57.9, U29.23
C457: JP57.10, U29.22
C458: JP57.11, U29.21
C459: JP57.12, U29.20
C460: JP57.13, U29.19
C461: JP57.14, U29.18
C462: JP57.15, U29.17
C463: JP57.16, U29.16
C464: JP59.1, U30.9
C465: JP59.2, U30.8
C466: JP59.3, U30.7
C467: JP59.4, U30.6
C468: JP59.5, U30.5
C469: JP59.6, U30.4
C470: JP59.7, U30.3
C471: JP59.8, U30.2
C472: JP59.9, U30.23
C473: JP59.10, U30.22
C474: JP59.11, U30.21
C475: JP59.12, U30.20
C476: JP59.13, U30.19
C477: JP59.14, U30.18
C478: JP59.15, U30.17
C479: JP59.16, U30.16
C480: JP61.1, U31.9
C481: JP61.2, U31.8
C482: JP61.3, U31.7
C483: JP61.4, U31.6
C484: JP61.5, U31.5
C485: JP61.6, U31.4
C486: JP61.7, U31.3
C487: JP61.8, U31.2
C488: JP61.9, U31.23
C489: JP61.10, U31.22
C490: JP61.11, U31.21
C491: JP61.12, U31.20
C492: JP61.13, U31.19
C493: JP61.14, U31.18
C494: JP61.15, U31.17
C495: JP61.16, U31.16
C496: JP63.1, U32.9
C497: JP63.2, U32.8
C498: JP63.3, U32.7
C499: JP63.4, U32.6
C500: JP63.5, U32.5
C501: JP63.6, U32.4
C502: JP63.7, U32.3
C503: JP63.8, U32.2
C504: JP63.9, U32.23
C505: JP63.10, U32.22
C506: JP63.11, U32.21
C507: JP63.12, U32.20
C508: JP63.13, U32.19
C509: JP63.14, U32.18
C510: JP63.15, U32.17
C511: JP63.16, U32.16
C512: JP65.1, U33.9
C513: JP65.2, U33.8
C514: JP65.3, U33.7
C515: JP65.4, U33.6
C516: JP65.5, U33.5
C517: JP65.6, U33.4
C518: JP65.7, U33.3
C519: JP65.8, U33.2
C520: JP65.9, U33.23
C521: JP65.10, U33.22
C522: JP65.11, U33.21
C523: JP65.12, U33.20
C524: JP65.13, U33.19
C525: JP65.14, U33.18
C526: JP65.15, U33.17
C527: JP65.16, U33.16
C528: JP67.1, U34.9
C529: JP67.2, U34.8
C530: JP67.3, U34.7
C531: JP67.4, U34.6
C532: JP67.5, U34.5
C533: JP67.6, U34.4
C534: JP67.7, U34.3
C535: JP67.8, U34.2
C536: JP67.9, U34.23
C537: JP67.10, U34.22
C538: JP67.11, U34.21
C539: JP67.12, U34.20
C540: JP67.13, U34.19
C541: JP67.14, U34.18
C542: JP67.15, U34.17
C543: JP67.16, U34.16
C544: JP69.1, U35.9
C545: JP69.2, U35.8
C546: JP69.3, U35.7
C547: JP69.4, U35.6
C548: JP69.5, U35.5
C549: JP69.6, U35.4
C550: JP69.7, U35.3
C551: JP69.8, U35.2
C552: JP69.9, U35.23
C553: JP69.10, U35.22
C554: JP69.11, U35.21
C555: JP69.12, U35.20
C556: JP69.13, U35.19
C557: JP69.14, U35.18
C558: JP69.15, U35.17
C559: JP69.16, U35.16
C560: JP71.1, U36.9
C561: JP71.2, U36.8
C562: JP71.3, U36.7
C563: JP71.4, U36.6
C564: JP71.5, U36.5
C565: JP71.6, U36.4
C566: JP71.7, U36.3
C567: JP71.8, U36.2
C568: JP71.9, U36.23
C569: JP71.10, U36.22
C570: JP71.11, U36.21
C571: JP71.12, U36.20
C572: JP71.13, U36.19
C573: JP71.14, U36.18
C574: JP71.15, U36.17
C575: JP71.16, U36.16
EN: JP3.3, R1.2, U1.15
EN1: JP4.3, R2.2, U2.15
EN2: JP6.3, R3.2, U3.15
EN3: JP8.3, R4.2, U4.15
EN4: JP10.3, R5.2, U5.15
EN5: JP12.3, R6.2, U6.15
EN6: JP14.3, R7.2, U7.15
EN7: JP16.3, R8.2, U8.15
EN8: JP18.3, R9.2, U9.15
EN9: JP20.3, R10.2, U10.15
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

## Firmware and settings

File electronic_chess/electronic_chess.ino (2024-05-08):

#include "src/Display.h"
#include "src/Board.h"

#include "src/utils/Constants.h"
#include "src/utils/PinDefinitions.h"

#include <FastLED.h>
#include <MFRC522.h>

#include <SPI.h>

#include <cstdint>

/* **************************************** Board **************************************** */
chess::Board board;
/* **************************************** Board **************************************** */

/* **************************************** LED **************************************** */
CRGB leds[LED_COUNT];
bool onMove = false;

void ledSetup() {
  FastLED.addLeds<WS2812B, PIN_LED_DATA, GRB>(leds, LED_COUNT);

  ledSetColor(CRGB::Red);
  delay(250);
  ledSetColor(CRGB::Green);
  delay(250);
  ledSetColor(CRGB::Blue);
  delay(250);

  ledReset();
}

void ledReset() {
  for(int i = 0; i < LED_COUNT; i++) {
    leds[i] = CRGB::Black;
  }

  FastLED.show();
}

void ledSetColor(CRGB color) {
  for(int i = 0; i < LED_COUNT; i++) {
    leds[i] = color;
  }

  FastLED.show();
}
/* **************************************** LED **************************************** */

/* **************************************** MFRC522 **************************************** */
MFRC522 mfrc522(PIN_NFC_SS, PIN_NFC_RST);
MFRC522::StatusCode status;

char tagData[] = "e-chess";
char piecesList[] = "PpRrNnBbQqKk";
byte buffer[18];
byte size = sizeof(buffer);
uint8_t pageAddr = 0x06;

char nfcBoard[64];

uint64_t nfcVersion = 0;
uint64_t nfcAntena  = 0;

int srcSqr = -1;
int trgSqr = -1;

void setAddr(int addr) {
  digitalWrite(PIN_EN_0, HIGH);
  digitalWrite(PIN_EN_1, HIGH);
  digitalWrite(PIN_EN_2, HIGH);
  digitalWrite(PIN_EN_3, HIGH);
  digitalWrite(PIN_ADDR0, bitRead(addr, 0) ? HIGH : LOW);
  digitalWrite(PIN_ADDR1, bitRead(addr, 1) ? HIGH : LOW);
  digitalWrite(PIN_ADDR2, bitRead(addr, 2) ? HIGH : LOW);
  digitalWrite(PIN_ADDR3, bitRead(addr, 3) ? HIGH : LOW);
  
  switch(addr / 16) {
    case 0:
      digitalWrite(PIN_EN_0, LOW);
      break;
    case 1:
      digitalWrite(PIN_EN_1, LOW);
      break;

    case 2:
      digitalWrite(PIN_EN_2, LOW);
      break;

    case 3:    
      digitalWrite(PIN_EN_3, LOW);
      break;
  }
  delay(1);
}

void setupReaders() {
  pinMode(PIN_EN_0, OUTPUT);
  pinMode(PIN_EN_1, OUTPUT);
  pinMode(PIN_EN_2, OUTPUT);
  pinMode(PIN_EN_3, OUTPUT);

  pinMode(PIN_ADDR0, OUTPUT);
  pinMode(PIN_ADDR1, OUTPUT);
  pinMode(PIN_ADDR2, OUTPUT);
  pinMode(PIN_ADDR3, OUTPUT);

  SPI.begin();

  for(int i = READER_FROM; i < READER_CNT; i++) {
    if(i % 16 == 0) Serial.println("");
    if(i % 8 == 0) Serial.println("");
    
    setAddr(i);

    /*Serial.print("Setting up reader id: ");
    Serial.print(i);
    Serial.print(" > ");*/

    mfrc522.PCD_Init();
    int numTrials = 0;

    for(int j = 0; j < 10; j++){
      mfrc522.PCD_SetAntennaGain(ANTENA_GAIN);
      if(mfrc522.PCD_GetAntennaGain() == ANTENA_GAIN){
        numTrials++;
      }
    }

    /*if(numTrials == 10) Serial.print("ok  > ");
    else Serial.print("nok > ");
    if(mfrc522.PCD_ReadRegister(mfrc522.VersionReg) == 0x92) Serial.println("0x92");
    else Serial.println("version nok");*/

    delay(1);
    mfrc522.PCD_AntennaOff();
  }
}

char readTag() {
  char retVal = ' ';
  mfrc522.PCD_AntennaOn();
  mfrc522.PCD_SetAntennaGain(ANTENA_GAIN);
  delay(1);
  
  if ( ! mfrc522.PICC_IsNewCardPresent()) return ' ';
	if ( ! mfrc522.PICC_ReadCardSerial()) return ' ';

  status = (MFRC522::StatusCode) mfrc522.MIFARE_Read(pageAddr, buffer, &size);
  if (status != MFRC522::STATUS_OK) return ' ';

  mfrc522.PCD_AntennaOff();
  delay(1);

  for(int i = 0; i < 7; i++) if(buffer[i] != tagData[i]) return ' ';
  for(int i = 0; i < 12; i++) if(buffer[15] == piecesList[i]) return buffer[15];
  
  return ' ';
}

void showPiecesColor() {
      for(int i = 0; i < 64; i++) {
    switch(nfcBoard[i]) {
      case 'P':
      case 'R':
      case 'N':
      case 'B':
      case 'Q':
      case 'K':
        leds[i] = CRGB::Blue;
        break;

      case 'p':
      case 'r':
      case 'n':
      case 'b':
      case 'q':
      case 'k':
        leds[i] = CRGB::Green;
        break;

      default:
      case ' ':
        leds[i] = CRGB::Black;
        break;
    }
  }

  FastLED.show();
}

void showPiecesType() {
    for(int i = 0; i < 64; i++) {
    switch(nfcBoard[i]) {
      case 'P':
      case 'p':
        leds[i] = CRGB::Red;
        break;

      case 'R':
      case 'r':
        leds[i] = CRGB::Green;
        break;

      case 'N':
      case 'n':
        leds[i] = CRGB::Blue;
        break;

      case 'B':
      case 'b':
        leds[i] = CRGB::Purple;
        break;
      
      case 'Q':
      case 'q':
        leds[i] = CRGB::Yellow;
        break;

      case 'K':
      case 'k':
        leds[i] = CRGB::White;
        break;

      default:
      case ' ':
        leds[i] = CRGB::Black;
        break;
    }
  }

  FastLED.show();
}

void readNFCs() {
  for(int i = READER_FROM; i < READER_CNT; i++) {
    setAddr(i);
    char tmpPiece = readTag();
    if(tmpPiece == ' ') {
      if(tmpPiece != nfcBoard[i]) tmpPiece = readTag(); //read again
    } 
    nfcBoard[i] = tmpPiece;
  }
}
/* **************************************** MFRC522 **************************************** */

/* **************************************** CONTROLL **************************************** */
#define PADDLE_NONE 0
#define PADDLE_WHITE 1
#define PADDLE_BLACK -1

int paddleSide = PADDLE_NONE;

unsigned long _lastButtonPressed = millis();
unsigned long _lastPaddlePressed = millis();
int counter = 0;
int lastCounter = 0;

void read_paddleW() {
  unsigned long currentTime = millis();
  if(paddleSide != PADDLE_WHITE && (currentTime - _lastPaddlePressed) > 100) {
    paddleSide = PADDLE_WHITE;
    _lastPaddlePressed = currentTime;
    //Serial.println("Paddle White");

    board.setOnMove(paddleSide);
  }
}

void read_paddleB() {
  unsigned long currentTime = millis();
  if(paddleSide != PADDLE_BLACK && (currentTime - _lastPaddlePressed) > 100) {
    paddleSide = PADDLE_BLACK;
    _lastPaddlePressed = currentTime;
    //Serial.println("Paddle Black");
    board.setOnMove(paddleSide);
  }
}

void read_button() {
  unsigned long currentTime = millis();
  if((currentTime - _lastButtonPressed) > 100) {
    //Serial.println("Button pressed");
    _lastButtonPressed = currentTime;

    board.start();
  }
}

void read_encoder() { 
  static uint8_t old_AB = 3;
  static int8_t encval = 0;
  static const int8_t enc_states[]  = {0,-1,1,0,1,0,0,-1,-1,0,0,1,0,1,-1,0};

  old_AB <<=2; 

  if (digitalRead(PIN_ENC_A)) old_AB |= 0x02;
  if (digitalRead(PIN_ENC_B)) old_AB |= 0x01;
  
  encval += enc_states[( old_AB & 0x0f )];

  if( encval > 3 ) {
    encval = 0;
    //Serial.println("Rottary turned R");
    displayRotaryTurned(1);
  }
  else if( encval < -3 ) {
    encval = 0;
    //Serial.println("Rottary turned L");
    displayRotaryTurned(-1);
  }
}
/* **************************************** CONTROLL **************************************** */

/* **************************************** CORE 0 **************************************** */ 
void setup() {
  board.setup();

  // Paddle interupts + setup
  pinMode(PIN_PADDLE_W, INPUT_PULLUP);
  pinMode(PIN_PADDLE_B, INPUT_PULLUP);  
  
  attachInterrupt(digitalPinToInterrupt(PIN_PADDLE_W), read_paddleW, RISING);
  attachInterrupt(digitalPinToInterrupt(PIN_PADDLE_B), read_paddleB, RISING);

  paddleSide = !digitalRead(PIN_PADDLE_W) ? PADDLE_WHITE : PADDLE_BLACK;
  board.setOnMove(paddleSide);

  // Encoder interupts + setup
  pinMode(PIN_ENC_A, INPUT_PULLUP);
  pinMode(PIN_ENC_B, INPUT_PULLUP);
  pinMode(PIN_ENC_BUTTON, INPUT_PULLUP);

  attachInterrupt(digitalPinToInterrupt(PIN_ENC_A), read_encoder, CHANGE);
  attachInterrupt(digitalPinToInterrupt(PIN_ENC_B), read_encoder, CHANGE);
  attachInterrupt(digitalPinToInterrupt(PIN_ENC_BUTTON), read_button, RISING);

  displaySetup();
  displayDrawBoard();
  displayDrawPieces(board._actualBoard);
  displayDrawTime(board.getTimeWhite(),board.getTimeBlack(), paddleSide);
}

void loop() {
  board.update();

  displayDrawBoard();
  displayDrawPieces(board._actualBoard);
  displayDrawTime(board.getTimeWhite(),board.getTimeBlack(),paddleSide);

  showPiecesColor();
  delay(250);
}
/* **************************************** CORE 0 **************************************** */

/* **************************************** CORE 1 **************************************** */
void setup1() {
  Serial.begin(115200);
  
  ledSetup();

  setupReaders();
}

void loop1() {
  readNFCs();
  board.setDetectedPosition(nfcBoard);
}
/* **************************************** CORE 1 **************************************** */

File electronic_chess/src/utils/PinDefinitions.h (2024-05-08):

#pragma once

//Encoder
#define PIN_ENC_BUTTON 2
#define PIN_ENC_A 3
#define PIN_ENC_B 4

//Paddle
#define PIN_PADDLE_W 21
#define PIN_PADDLE_B 20

//Adressable leds
#define PIN_LED_DATA 5

//NFC
#define PIN_NFC_RST 0
#define PIN_NFC_SS  17

//Multiplexor
#define PIN_EN_0  9
#define PIN_EN_1  8
#define PIN_EN_2  7
#define PIN_EN_3  6

#define PIN_ADDR0 22
#define PIN_ADDR1 26
#define PIN_ADDR2 27
#define PIN_ADDR3 28

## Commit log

2024-05-08 electronich_chess init files
    [Analog-Digital-Mux-Breakout.brd, Analog-Digital-Mux-Breakout.sch, Analog-Digital-Mux_Breakout_Panel_v11.brd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]
2024-05-08 Update README.md in pcb_
2024-05-08 Update README.md board

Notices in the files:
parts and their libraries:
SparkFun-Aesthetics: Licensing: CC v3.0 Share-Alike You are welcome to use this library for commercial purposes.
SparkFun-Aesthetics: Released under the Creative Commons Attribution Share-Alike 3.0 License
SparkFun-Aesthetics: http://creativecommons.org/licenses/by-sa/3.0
